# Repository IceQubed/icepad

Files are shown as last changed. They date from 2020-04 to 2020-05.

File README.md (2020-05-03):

# icepad

This is a 4 by 4 ortholinear keypad. It may be used as a numpad or macropad. It includes per-key LEDs and two potentiometer knobs.

## Prerequisites / Installation

This project was created using KiCad 5. 

The board is based around an STM32F042K6 microcontroller - code is available [here](https://github.com/IceQubed/icepad-sw).

## License

This work is licensed under a [Creative Commons Attribution-ShareAlike 4.0 International License](http://creativecommons.org/licenses/by-sa/4.0/).

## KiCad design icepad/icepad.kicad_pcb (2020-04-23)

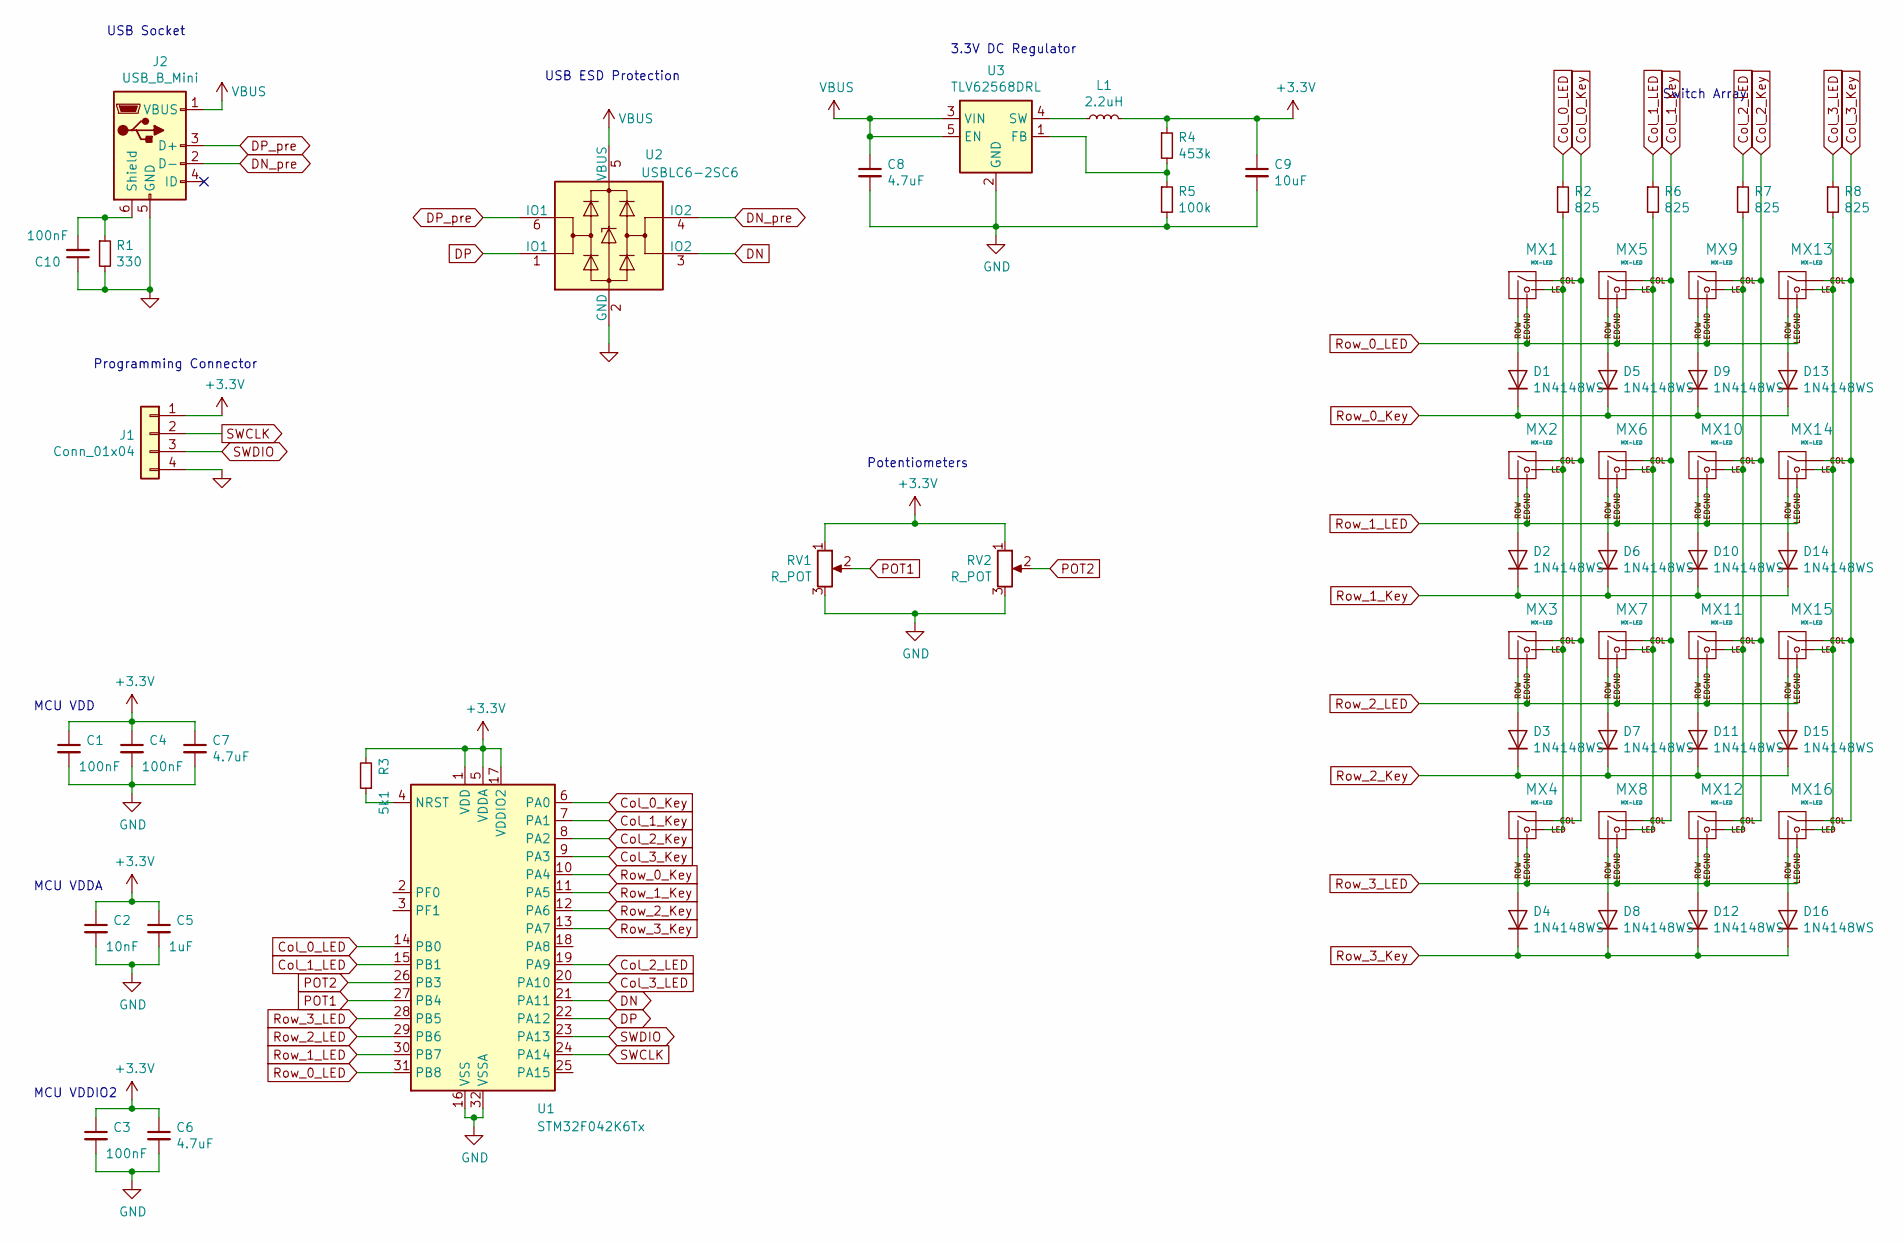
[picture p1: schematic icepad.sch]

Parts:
C1, C3, C4, C10: 100nF; C_0805_2012Metric; LCSC C49678
C2: 10nF; C_0805_2012Metric; LCSC C1710
C5: 1uF; C_0805_2012Metric; LCSC C28323
C6, C7, C8: 4.7uF; C_0805_2012Metric; LCSC C1779
C9: 10uF; C_0805_2012Metric; LCSC C15850
D1, D2, D3, D4, D5, D6, D7, D8, D9, D10, D11, D12, D13, D14, D15, D16: 1N4148WS; D_SOD-323; LCSC C2128
J1: Conn_01x04; PinHeader_1x04_P2.54mm_Horizontal
J2: USB_B_Mini; USB_Mini_B_Female_548190519
L1: 2.2uH; L_0805_2012Metric; LCSC C1043
MX1, MX2, MX3, MX4, MX5, MX6, MX7, MX8, MX9, MX10, MX11, MX12, MX13, MX14, MX15, MX16: MX-LED; MXOnly-1U
R1: 330; R_0805_2012Metric; LCSC C17630
R2, R6, R7, R8: 825; R_0805_2012Metric; LCSC C17839
R3: 5k1; R_0805_2012Metric; LCSC C27834
R4: 453k; R_0805_2012Metric; LCSC C17702
R5: 100k; R_0805_2012Metric; LCSC C17407
RV1, RV2: R_POT; RK09K1130A5R
U1: STM32F042K6Tx; LQFP-32_7x7mm_P0.8mm; LCSC C69216
U2: USBLC6-2SC6; SOT-23-6; LCSC C7519
U3: TLV62568DRL; SOT-563; LCSC C398370

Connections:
+3V3: C1.1, C2.1, C3.1, C4.1, C5.1, C6.1, C7.1, C9.1, J1.1, L1.2, R3.2, R4.1, RV1.1, RV2.1, U1.1 (VDD), U1.5 (VDDA), U1.17 (VDDIO2)
Col_0_Key: MX1.1 (COL), MX2.1 (COL), MX3.1 (COL), MX4.1 (COL), U1.6 (PA0)
Col_0_LED: R2.1, U1.14 (PB0)
Col_1_Key: MX5.1 (COL), MX6.1 (COL), MX7.1 (COL), MX8.1 (COL), U1.7 (PA1)
Col_1_LED: R6.1, U1.15 (PB1)
Col_2_Key: MX9.1 (COL), MX10.1 (COL), MX11.1 (COL), MX12.1 (COL), U1.8 (PA2)
Col_2_LED: R7.1, U1.19 (PA9)
Col_3_Key: MX13.1 (COL), MX14.1 (COL), MX15.1 (COL), MX16.1 (COL), U1.9 (PA3)
Col_3_LED: R8.1, U1.20 (PA10)
DN: U1.21 (PA11), U2.3 (IO2)
DN_pre: J2.2 (D-), U2.4 (IO2)
DP: U1.22 (PA12), U2.1 (IO1)
DP_pre: J2.3 (D+), U2.6 (IO1)
GND: C1.2, C2.2, C3.2, C4.2, C5.2, C6.2, C7.2, C8.2, C9.2, C10.1, J1.4, J2.5 (GND), R1.2, R5.2, RV1.3, RV2.3, U1.16 (VSS), U1.32 (VSSA), U2.2 (GND), U3.2 (GND)
unnamed: C10.2, J2.6 (Shield), R1.1
unnamed: D1.2 (A), MX1.2 (ROW)
unnamed: D2.2 (A), MX2.2 (ROW)
unnamed: D3.2 (A), MX3.2 (ROW)
unnamed: D4.2 (A), MX4.2 (ROW)
unnamed: D5.2 (A), MX5.2 (ROW)
unnamed: D6.2 (A), MX6.2 (ROW)
unnamed: D7.2 (A), MX7.2 (ROW)
unnamed: D8.2 (A), MX8.2 (ROW)
unnamed: D9.2 (A), MX9.2 (ROW)
unnamed: D10.2 (A), MX10.2 (ROW)
unnamed: D11.2 (A), MX11.2 (ROW)
unnamed: D12.2 (A), MX12.2 (ROW)
unnamed: D13.2 (A), MX13.2 (ROW)
unnamed: D14.2 (A), MX14.2 (ROW)
unnamed: D15.2 (A), MX15.2 (ROW)
unnamed: D16.2 (A), MX16.2 (ROW)
unnamed: L1.1, U3.4 (SW)
unnamed: MX1.3 (LED), MX2.3 (LED), MX3.3 (LED), MX4.3 (LED), R2.2
unnamed: MX5.3 (LED), MX6.3 (LED), MX7.3 (LED), MX8.3 (LED), R6.2
unnamed: MX9.3 (LED), MX10.3 (LED), MX11.3 (LED), MX12.3 (LED), R7.2
unnamed: MX13.3 (LED), MX14.3 (LED), MX15.3 (LED), MX16.3 (LED), R8.2
unnamed: R3.1, U1.4 (NRST)
unnamed: R4.2, R5.1, U3.1 (FB)
POT1: RV1.2, U1.27 (PB4)
POT2: RV2.2, U1.26 (PB3)
Row_0_Key: D1.1 (K), D5.1 (K), D9.1 (K), D13.1 (K), U1.10 (PA4)
Row_0_LED: MX1.4 (LEDGND), MX5.4 (LEDGND), MX9.4 (LEDGND), MX13.4 (LEDGND), U1.31 (PB8)
Row_1_Key: D2.1 (K), D6.1 (K), D10.1 (K), D14.1 (K), U1.11 (PA5)
Row_1_LED: MX2.4 (LEDGND), MX6.4 (LEDGND), MX10.4 (LEDGND), MX14.4 (LEDGND), U1.30 (PB7)
Row_2_Key: D3.1 (K), D7.1 (K), D11.1 (K), D15.1 (K), U1.12 (PA6)
Row_2_LED: MX3.4 (LEDGND), MX7.4 (LEDGND), MX11.4 (LEDGND), MX15.4 (LEDGND), U1.29 (PB6)
Row_3_Key: D4.1 (K), D8.1 (K), D12.1 (K), D16.1 (K), U1.13 (PA7)
Row_3_LED: MX4.4 (LEDGND), MX8.4 (LEDGND), MX12.4 (LEDGND), MX16.4 (LEDGND), U1.28 (PB5)
SWCLK: J1.2, U1.24 (PA14)
SWDIO: J1.3, U1.23 (PA13)
VBUS: C8.1, J2.1 (VBUS), U2.5 (VBUS), U3.3 (VIN), U3.5 (EN)

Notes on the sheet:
USB ESD Protection
USB Socket
3.3V DC Regulator
Switch Array
MCU VDD
MCU VDDA
MCU VDDIO2
Programming Connector
Potentiometers

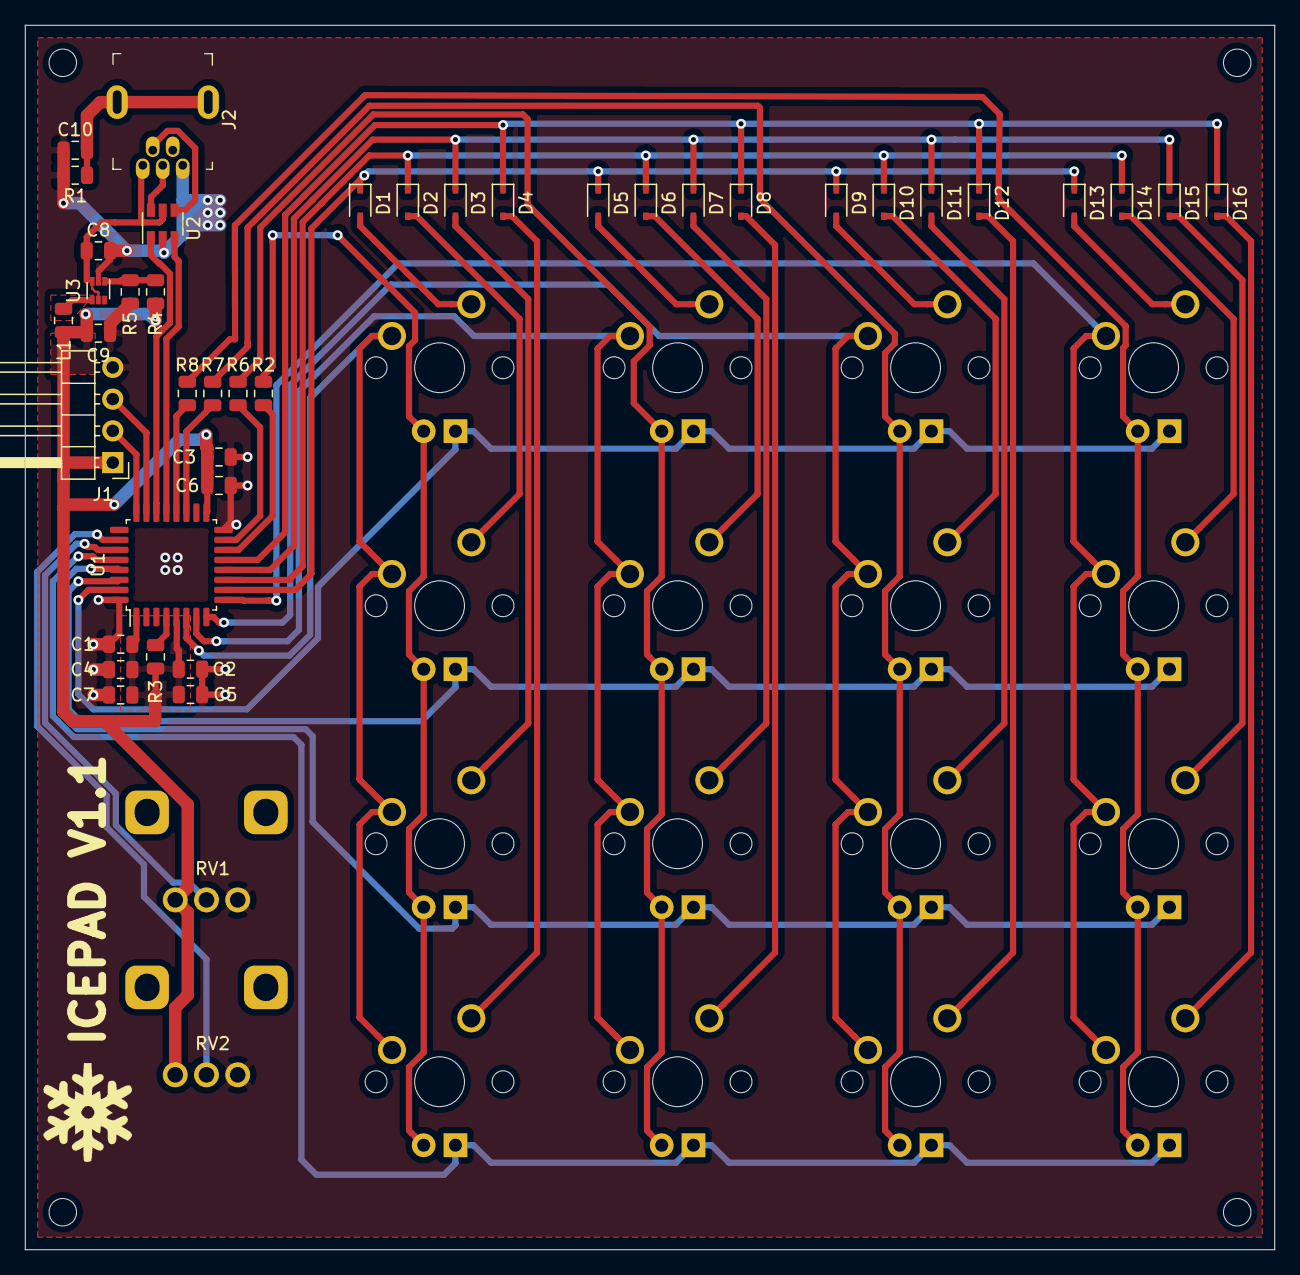
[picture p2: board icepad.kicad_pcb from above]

Board: 2 copper layers, 100.0 x 98.0 mm, 62 parts (0 on the bottom side), 51 nets.

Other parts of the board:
MNT: MountingHole_2.2mm_M2
MNT#2, MNT#3, MNT#4: MountingHole_2.2mm_M2

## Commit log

2020-02-06 initialised kicad project folder
    [icepad.kicad_pcb, icepad.sch]
2020-02-06 wired up switch matrix
    [icepad.sch]
2020-02-06 added mcu
    [icepad.sch]
2020-02-06 removed old submodule
    [icepad.sch]
2020-02-06 added usb c connector
2020-02-06 schematic edits
    [icepad.sch]
2020-02-08 Added DC DC converter and decoupling caps for MCU
    [icepad.sch]
2020-02-08 added NC pins
    [icepad.sch]
2020-02-08 Added PCB footprint and associated schematic to footprints
    [icepad.sch]
2020-02-10 set up key grid on PCB layout
    [icepad.kicad_pcb, icepad.sch]
2020-02-10 routed MCU and connector
    [icepad.kicad_pcb]
2020-02-10 completed routing without led
    [icepad.kicad_pcb, icepad.sch]
2020-04-22 added jlcpcb stock and new pcb design
    [icepad.kicad_pcb, icepad.sch]
2020-04-22 complete new pcba design
    [icepad.kicad_pcb, icepad.sch]
2020-04-23 Completed routing, added LED resistors
    [icepad.kicad_pcb, icepad.sch]
2020-04-23 added potentiometers and 3d models
    [icepad.kicad_pcb, icepad.sch]
2020-04-23 changed potentiometer
    [icepad.kicad_pcb, icepad.sch]
2020-05-03 as sent for production
    [icepad-B_Cu.gbr, icepad-B_Mask.gbr, icepad-B_Paste.gbr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]
